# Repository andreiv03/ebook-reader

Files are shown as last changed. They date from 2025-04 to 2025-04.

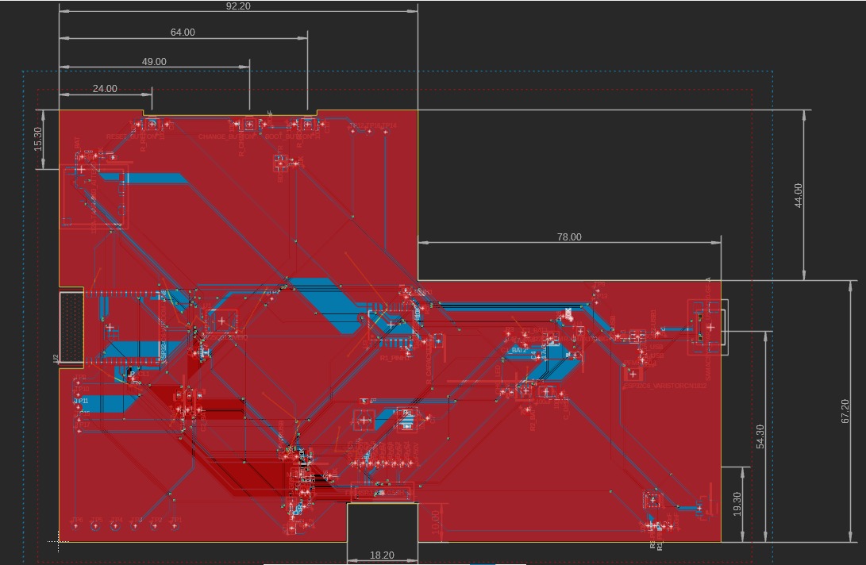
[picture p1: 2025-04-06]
images/pcb.jpg

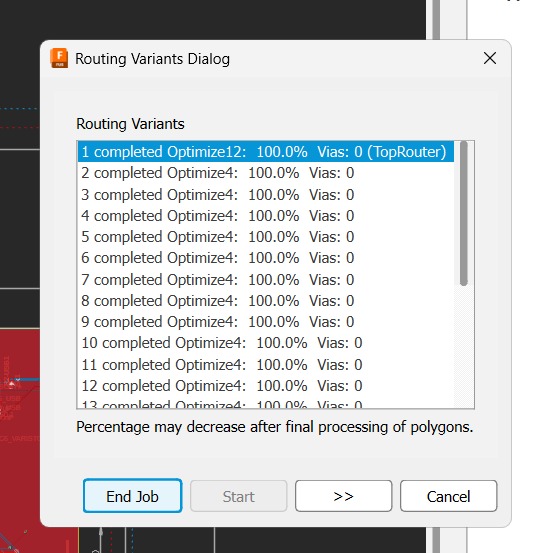
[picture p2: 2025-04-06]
images/autorouter.jpg

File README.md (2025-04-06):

# OpenBook E-book Reader

#### Autor: Voicu Andrei-Silviu

## Descriere generală

OpenBook este un e-reader open-source construit în jurul microcontrollerului ESP32-C6. Dispozitivul folosește un ecran e-paper de 7.5", senzori de mediu, monitorizare baterie și conectivitate USB-C & Wi-Fi.

## Diagramă bloc

```plaintext
         +---------------------+
         |      Li-Po Cell     |
         +---------+-----------+
                   |
                   v
         +---------------------+
         |   Battery Charger   |  <--- USB-C 5V
         |    MCP73832 IC      |
         +---------+-----------+
                   |
                   v
         +---------------------+
         |   3.3V Regulator    | ---> VCC (3.3V Rail)
         +---------+-----------+
                   |
        +----------+-----------+-----------------------+
        |          |           |                       |
        v          v           v                       v
   +---------+ +------------+ +------------------+ +------------------+
   | ESP32-C3| | E-Ink Disp | |   BME688 Sensor  | |   Push Buttons   |
   |   -C6   | |  (SPI 4W)  | |    (I2C Comm)    | |  (GPIO + RC net) |
   +----+----+ +------------+ +--------+---------+ +--------+---------+
        |                           ^                        ^
        |                           |                        |
        |                     Pull-up Res.             Debounce Filter
        |
        v
   +-----------------------------+
   |     USB Type-C Connector    |
   | ↔ USB Data to ESP32 UART    |
   |    + ESD & Termination      |
   +-----------------------------+
```

## Listă de componente (BOM)

| Componenta | Link | Datasheet
| --- | --- |---|
|BUTTON_CUSYOMV1|https://industry.panasonic.com/global/en/downloads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|https://industry.panasonic.com/global/en/downloads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
|ESP32_WROVER_EAGLE-LTSPICE_CC0402|https://componentsearchengine.com/part-view/CC0402MRX5R5BB106/YAGEO|https://componentsearchengine.com/Datasheets/2/CC0402MRX5R5BB106.pdf
| QWIIC_CONNECTORJS-1MM | https://www.snapeda.com/parts/PRT-14417/SparkFun/view-part/ |https://www.snapeda.com/parts/PRT-14417/SparkFun%20Electronics/datasheet/
|112A-TAAR-R03_ATTEND|https://store.comet.bg/en/Catalogue/Product/43497/|https://store.comet.bg/en/Catalogue/Product/43497/|
|ADAFRUIT_LEDCHIP-LED0603|https://www.snapeda.com/parts/KP-1608SURCK/Kingbright/view-part/?ref=search&t=LED%200603|https://www.snapeda.com/parts/KP-1608SURCK/Kingbright/datasheet/
|744043680IND_4828-WE-TPC_WRE|https://www.digikey.sg/en/models/1638515|https://www.we-online.com/components/products/datasheet/744043680.pdf
|ESP32_WROVER_EAGLE-LTSPICE_CC0402|https://componentsearchengine.com/Datasheets/2/CC0402MRX5R5BB106.pdf|https://componentsearchengine.com/part-view/CC0402MRX5R5BB106/YAGEO|
|CPH3225A|https://www.snapeda.com/parts/CPH3225A/Seiko+Instruments/view-part/?ref=eda|https://www.snapeda.com/parts/CPH3225A/Seiko%20Instruments/datasheet/|
|DS3231SN|https://www.snapeda.com/parts/DS3231SN%23/Analog+Devices/view-part/?ref=eda|https://www.snapeda.com/parts/DS3231SN%23/Analog%20Devices/datasheet/|
|SJ|https://grabcad.com/library/solder-jumpers-1||
|CPH3225A|https://www.snapeda.com/parts/CPH3225A/Seiko+Instruments/view-part/?ref=eda|https://www.snapeda.com/parts/CPH3225A/Seiko%20Instruments/datasheet/|
|MCP73831|https://www.digikey.com/en/models/1874108|https://ww1.microchip.com/downloads/aemDocuments/documents/APID/ProductDocuments/DataSheets/MCP73831-Family-Data-Sheet-DS20001984H.pdf|
|RCL_CPOL-EUCT3528|https://ro.mouser.com/ProductDetail/Vishay-Sprague/TR3B106K025C1300?qs=jCGqFXxTmLdffnuDkXzk1g%3D%3D|https://www.vishay.com/docs/40080/tr3.pdf|
|ESP32_WROVER_BME680_BME680|https://www.snapeda.com/parts/BME680/Bosch/view-part/?welcome=home|https://www.snapeda.com/parts/BME680/Bosch%20Sensortec/datasheet/|
|ESP32_WROVER_SPARKFUN-DISCRETESEMI_MOSFET_PCH-DMG2305UX-7|https://componentsearchengine.com/part-view/DMG2305UX-7/Diodes%20Incorporated|https://www.diodes.com//assets/Datasheets/DMG2305UX.pdf|
|BD5229G-TR|https://componentsearchengine.com/part-view/BD5229G-TR/ROHM%20Semiconductor|https://datasheet.datasheetarchive.com/originals/distributors/Datasheets_SAMA/f2b9741ef86007909f138d561a359946.pdf|
|ESP32C6_VARISTORCN1812|https://www.mouser.co.uk/ProductDetail/EPCOS-TDK/B72520T0350K062?qs=dEfas%2FXlABIszF52uu7vrg%3D%3D|https://www.tdk-electronics.tdk.com/inf/75/db/CTVS_14/Surge_protection_series.pdf|
|USBLC6-2SC6Y|https://www.snapeda.com/parts/USBLC6-2SC6Y/STMicroelectronics/view-part/?ref=eda|https://www.snapeda.com/parts/USBLC6-2SC6Y/STMicroelectronics/datasheet/|
|W25Q512JVEIQ|https://www.snapeda.com/parts/W25Q512JVEIQ/Winbond+Electronics/view-part/?ref=eda|https://www.snapeda.com/parts/W25Q512JVEIQ/Winbond%20Electronics/datasheet/|
|XC6220A331MR-G|https://componentsearchengine.com/part-view/XC6220A331MR-G/Torex|https://product.torexsemi.com/system/files/series/xc6220.pdf|
|ESP32-C6-WROOM-1-N8|https://www.snapeda.com/parts/ESP32-C6-WROOM-1-N8/Espressif+Systems/view-part/?ref=eda|https://www.snapeda.com/parts/ESP32-C6-WROOM-1-N8/Espressif%20Systems/datasheet/
| ESP32_WROVER_EAGLE-LTSPICE_RR0402  | https://www.snapeda.com/parts/RC0402FR-07226RL/Yageo/view-part/ |https://www.snapeda.com/parts/RC0402FR-07226RL/Yageo/datasheet/
|FH34SRJ-24S-0.5SH_99_|https://componentsearchengine.com/part-view/XC6220A331MR-G/Torex|https://product.torexsemi.com/system/files/series/xc6220.pdf|
|SAMACSYS_PARTS_USB4110-GF-A|https://componentsearchengine.com/part-view/USB4110-GF-A/GCT%20(GLOBAL%20CONNECTOR%20TECHNOLOGY)|https://gct.co/files/drawings/usb4110.pdf|
|MAX17048G+T10|https://www.snapeda.com/parts/MAX17048G+T10/Analog+Devices/view-part/?ref=eda|https://www.snapeda.com/parts/MAX17048G+T10/Analog%20Devices/datasheet/|
|PGB1010603MR|https://www.snapeda.com/parts/PGB1010603MR/Littelfuse/view-part/?ref=eda|https://www.snapeda.com/parts/PGB1010603MR/Littelfuse%20Inc./datasheet/|
|SI1308EDL-T1-GE3|https://componentsearchengine.com/part-view/SI1308EDL-T1-GE3/Vishay|https://componentsearchengine.com/Datasheets/1/SI1308EDL-T1-GE3.pdf|
|MBR0530|https://ro.mouser.com/ProductDetail/KYOCERA-AVX/SD0805S020S1R0?qs=jCA%252BPfw4LHbpkAoSnwrdjw%3D%3D|https://ro.mouser.com/datasheet/2/40/schottky-3165252.pdf|

## Componente principale

#### ESP32-C6-WROOM-1-N8
- MCU principal, Wi-Fi 6, Bluetooth 5
- Interfețe: SPI, I2C, UART, GPIO
- 160MHz, 512KB SRAM, 8MB Flash

#### Senzor BME688
- Măsoară: temperatură, umiditate, presiune, VOC
- I2C, consum redus: <1mA

#### Ecran E-Paper
- Diagonală: 7.5”
- Conectare prin SPI
- Consum 0 în stare statică

#### Sistem de Alimentare
- Baterie: 3.7V Li-Po 2500mAh
- Încărcare: MCP73831, max 1A
- Monitorizare: MAX17048 (Fuel Gauge)
- Consum tipic:
- Activ: ~150mA
- Standby: ~10mA
- Deep Sleep: <50µA
- Autonomie: ~250h la 10mA

#### Conectivitate USB-C
- Încărcare & date (USB 2.0)
- Protecție ESD: USBLC6-2SC6Y

## Alocare pini ESP32-C6

| *Pin ESP32-C6* | *Funcție* | *Componentă* | *Rol* |
|---|---|---|---|
| GPIO0 | BOOT_BUTTON | Buton | Mod boot la inițializare |
| GPIO1 | RESET_BUTTON | Buton | Reset manual |
| GPIO2 | CHANGE_BUTTON | Buton | Schimbare meniuri |
| GPIO3 | EPD_CS | Display E-Paper | Chip Select pentru SPI |
| GPIO4 | EPD_DC | Display E-Paper | Control Date/Comenzi |
| GPIO5 | EPD_RST | Display E-Paper | Reset display |
| GPIO6 | EPD_BUSY | Display E-Paper | Detectare stare refresh |
| GPIO7 | SPI_MOSI | Display, Flash, SD | Linii de date SPI |
| GPIO8 | SPI_MISO | Display, Flash, SD | Linie de date SPI (citire) |
| GPIO9 | SPI_SCK | Display, Flash, SD | Semnal de ceas SPI |
| GPIO10 | FLASH_CS | Memorie Flash | Chip Select pentru memorie |
| GPIO11 | SD_CS | Card Micro SD | Chip Select pentru card SD |
| GPIO12 | I2C_SDA | BME680, MAX17048, DS3231 | Linie de date pentru I2C |
| GPIO13 | I2C_SCL | BME680, MAX17048, DS3231 | Linie de ceas pentru I2C |
| GPIO14 | CHG_LED | LED | Indică procesul de încărcare |
| GPIO15 | UART_TX | Debugging | Transmitere date seriale |
| GPIO16 | UART_RX | Debugging | Recepție date seriale |
| GPIO17 | USB_D+ | USB-C | Linie de date USB pozitivă |
| GPIO18 | USB_D- | USB-C | Linie de date USB negativă |

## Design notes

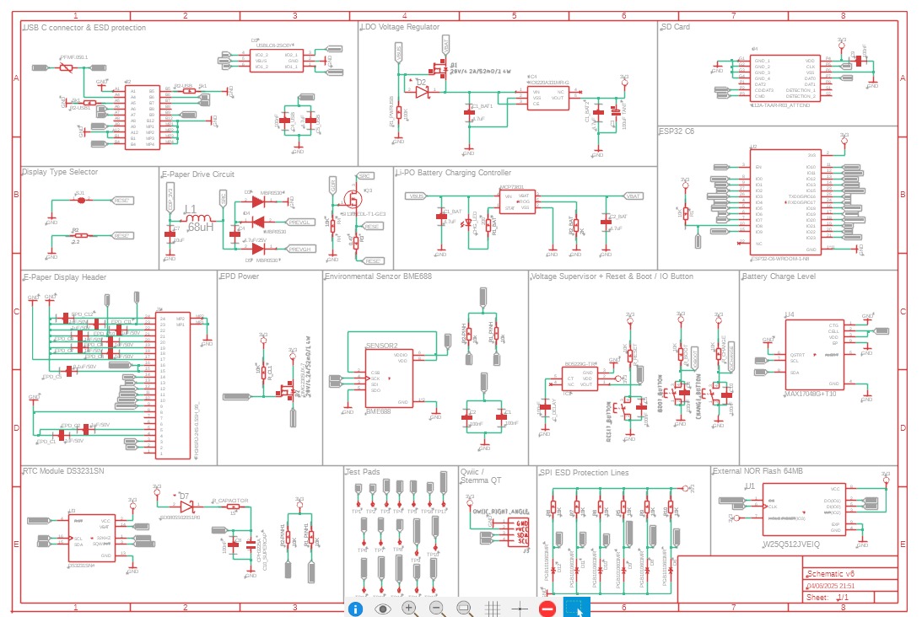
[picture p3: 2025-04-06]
images/schematic.jpg

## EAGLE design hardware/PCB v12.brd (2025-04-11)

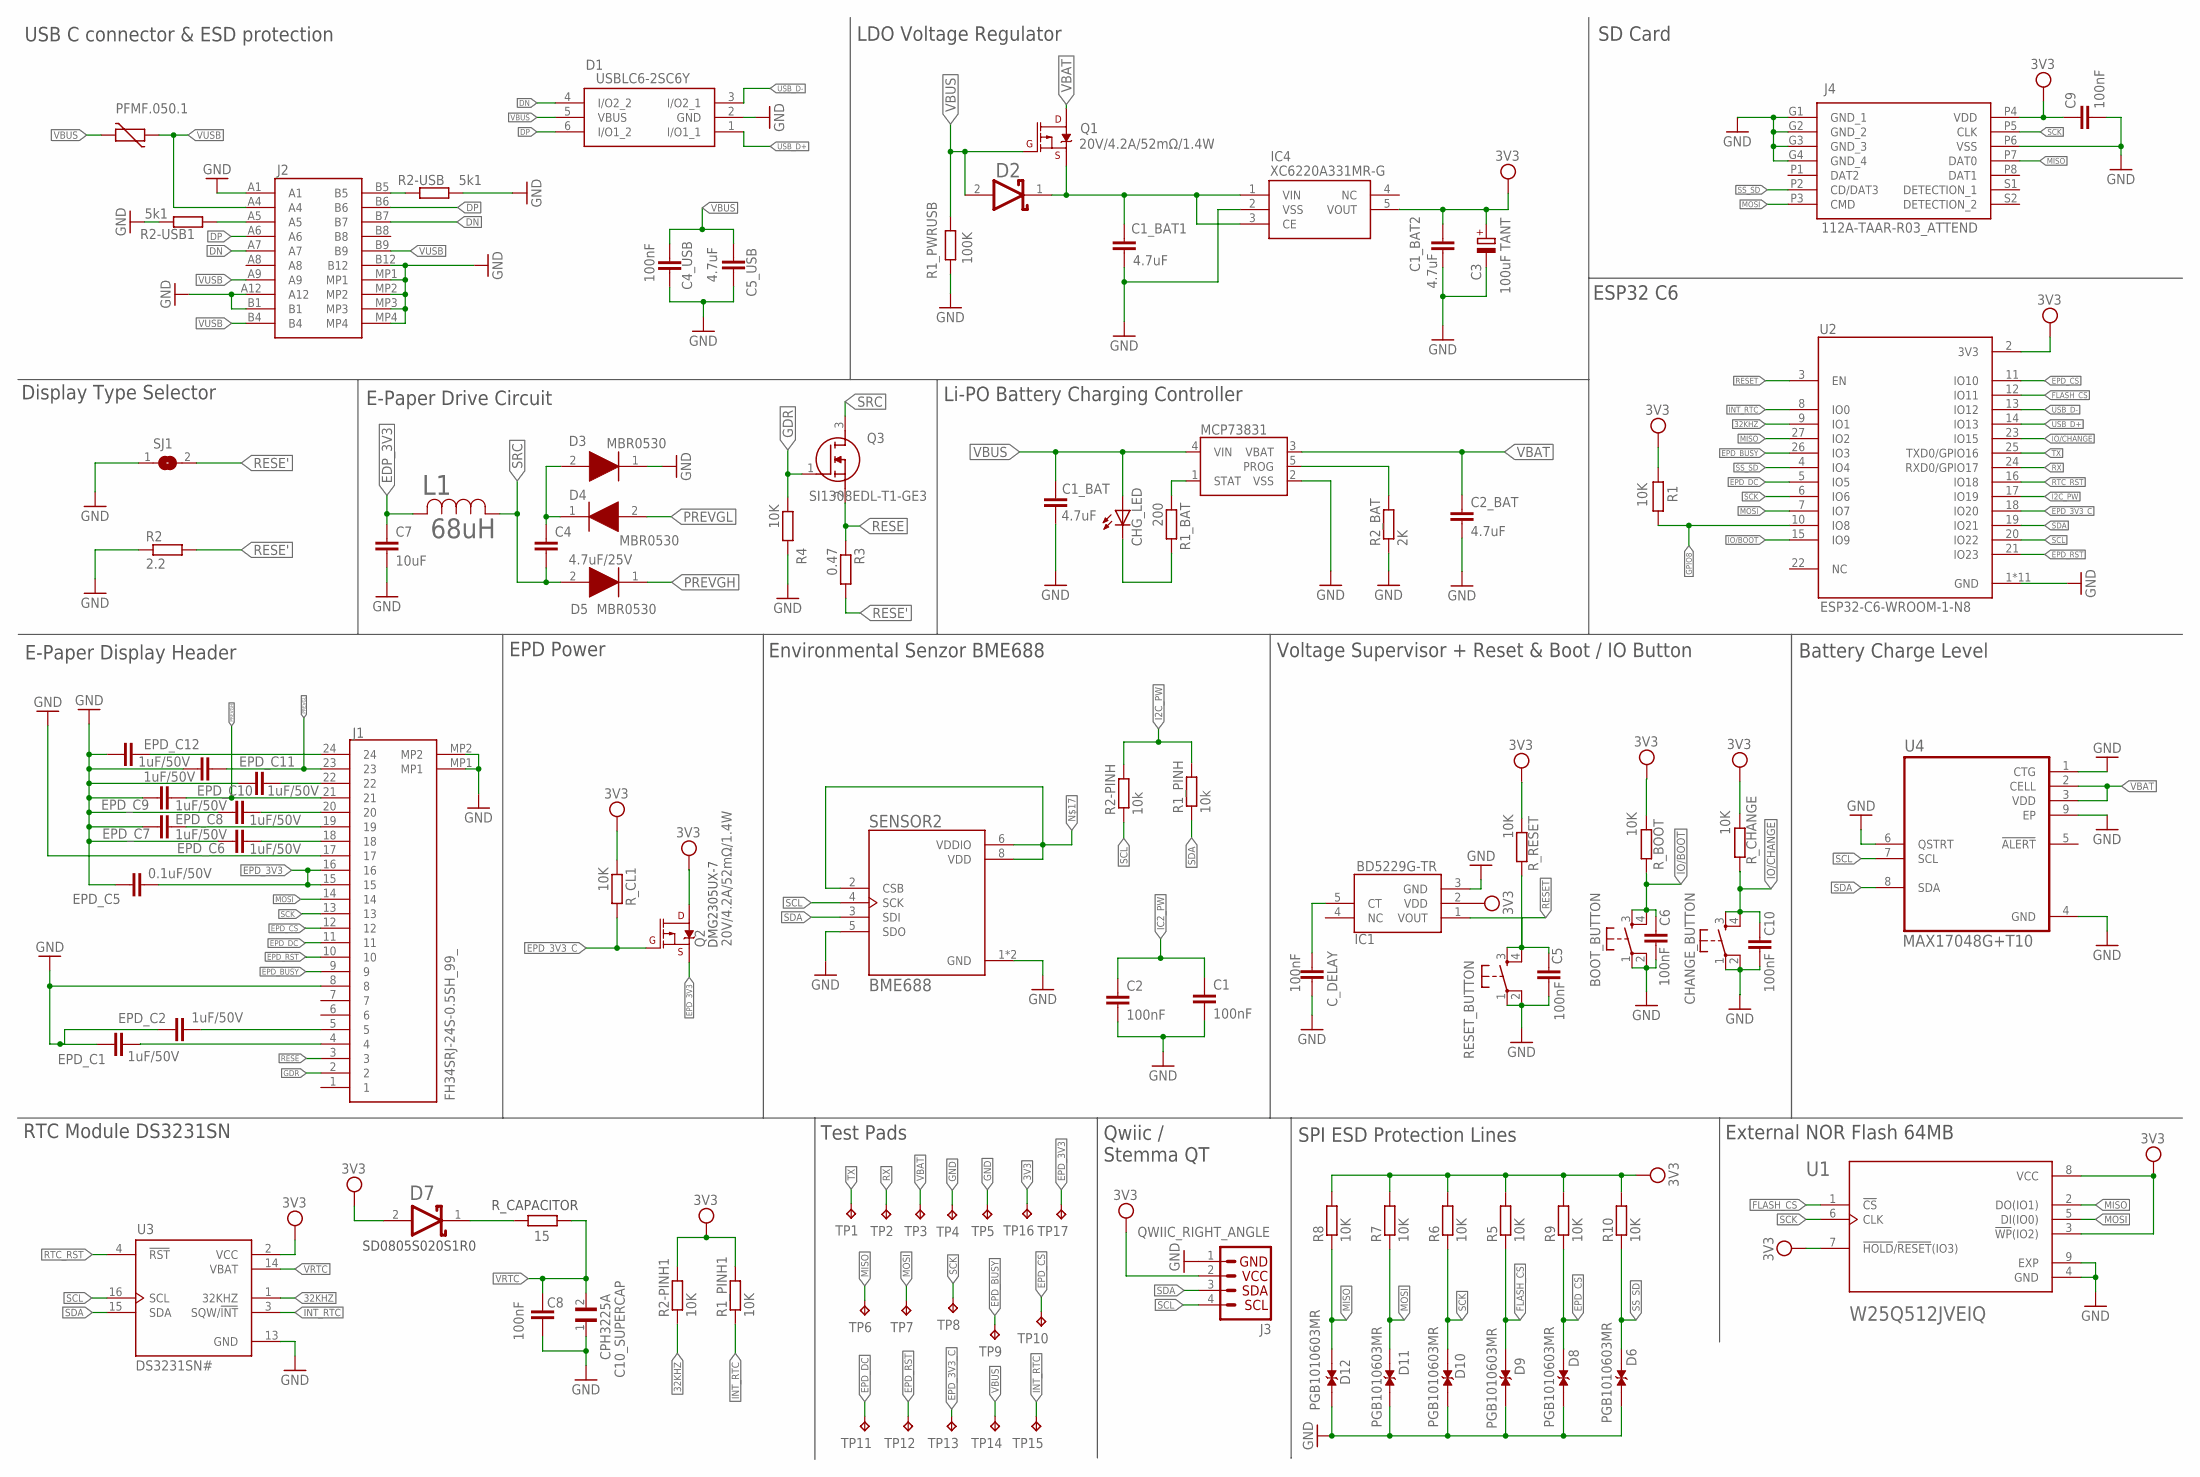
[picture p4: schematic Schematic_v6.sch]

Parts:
BOOT_BUTTON: BUTTON_CUSYOMV1; MYBUTTON
C1, C2, C4_USB, C8, C9: 100nF; ESP32_WROVER_EAGLE-LTSPICE_C0402
C1_BAT, C1_BAT1, C1_BAT2, C2_BAT, C5_USB: 4.7uF; ESP32_WROVER_EAGLE-LTSPICE_C0402
C3: 100uF TANT; RCL_CT3528
C4: 4.7uF/25V; ESP32_WROVER_EAGLE-LTSPICE_C0402
C5, C6, C10: 100nF; EAGLE-LTSPICE_C0402
C7: 10uF; ESP32_WROVER_EAGLE-LTSPICE_C0402
C10_SUPERCAP: CPH3225A; CAPCP3225X100N
CHANGE_BUTTON: BUTTON_CUSYOMV1; MYBUTTON
CHG_LED: CHG; ADAFRUIT_CHIP-LED0603
C_DELAY: 100nF; ESP32_WROVER_EAGLE-LTSPICE_C0402
D1: USBLC6-2SC6Y; SOT95P280X145-6N
D2, D7: ESP32_WROVER_AVX---SD0805S020S1R0_AVX_SD0805S020S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; ESP32_WROVER_AVX---SD0805S020S1R0_AVX_SD0805S020S1R0_0
D3, D4, D5: MBR0530; SOD3716X135N
D6, D8, D9, D10, D11, D12: PGB1010603MR; DIOC1608X36N
EPD_C1, EPD_C2, EPD_C6, EPD_C7, EPD_C8, EPD_C9, EPD_C10, EPD_C11, EPD_C12: 1uF/50V; EAGLE-LTSPICE_C0402
EPD_C5: 0.1uF/50V; EAGLE-LTSPICE_C0402
IC1: BD5229G-TR; SOT95P280X125-5N
IC4: XC6220A331MR-G; SOT95P280X120-5N
J1: FH34SRJ-24S-0.5SH_99_; FH34SRJ24S05SH99
J2: SAMACSYS_PARTS_USB4110-GF-A; SAMACSYS_PARTS_USB4110GFA
J3: QWIIC_RIGHT_ANGLE; JST04_1MM_RA
J4: 112A-TAAR-R03_ATTEND; 112ATAARR03ATTEND
L1: 68uH; IND_4828-WE-TPC_WRE
MCP73831: ESP32_WROVER_SPARKFUN-IC-POWER_MCP73831; ESP32_WROVER_SPARKFUN-IC-POWER_SOT23-5
PFMF.050.1: ESP32C6_VARISTORCN1812; ESP32C6_VARISTOR_CT/CN1812
Q1, Q2: 20V/4.2A/52mΩ/1.4W; ESP32_WROVER_SPARKFUN-DISCRETESEMI_SOT23-3
Q3: SI1308EDL-T1-GE3; SOT65P210X110-3N
R1, R1_PINH1, R2-PINH1, R4, R5, R6, R7, R8, R9, R10: 10K; ESP32_WROVER_EAGLE-LTSPICE_R0402
R1_BAT: 200; ESP32_WROVER_EAGLE-LTSPICE_R0402
R1_PINH, R2-PINH: 10k; ESP32_WROVER_EAGLE-LTSPICE_R0402
R1_PWRUSB: 100K; ESP32_WROVER_EAGLE-LTSPICE_R0402
R2: 2.2; ESP32_WROVER_EAGLE-LTSPICE_R0402
R2-USB, R2-USB1: 5k1; ESP32_WROVER_EAGLE-LTSPICE_R0402
R2_BAT: 2K; ESP32_WROVER_EAGLE-LTSPICE_R0402
R3: 0.47; ESP32_WROVER_EAGLE-LTSPICE_R0402
RESET_BUTTON: BUTTON_CUSYOMV1; MYBUTTON
R_BOOT: 10K; ESP32_WROVER_EAGLE-LTSPICE_R0402
R_CAPACITOR: 15; ESP32_WROVER_EAGLE-LTSPICE_R0402
R_CHANGE: 10K; ESP32_WROVER_EAGLE-LTSPICE_R0402
R_CL1: 10K; ESP32_WROVER_EAGLE-LTSPICE_R0402
R_RESET: 10K; ESP32_WROVER_EAGLE-LTSPICE_R0402
SENSOR2: BME688; ESP32_WROVER_BME680_PSON80P300X300X100-8N
SJ1: SJ1; SJ
TP1, TP2, TP3, TP4, TP5, TP6, TP7, TP8, TP9, TP10, TP11, TP12, TP13, TP14, TP15, TP16, TP17: TPTP20R; TP20R
U1: W25Q512JVEIQ; SON127P600X800X80-9N
U2: ESP32-C6-WROOM-1-N8; XCVR_ESP32-C6-WROOM-1-N8
U3: DS3231SN#; SOIC127P1032X265-16N
U4: MAX17048G+T10; SON50P200X200X80-9N

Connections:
3V3: C1_BAT2.1, C3.+, C9.1, D7.2 (ANODE), IC4.5 (VOUT), J3.2, J4.P4 (VDD), Q2.3 (D), R1.1, R1_PINH1.2, R2-PINH1.2, R5.2, R6.2, R7.2, R8.2, R9.2, R10.2, R_BOOT.2, R_CHANGE.2, R_CL1.1, R_RESET.2, TP16.TP, U1.3 (!WP!(IO2)), U1.7 (!HOLD!/!RESET!(IO3)), U1.8 (VCC), U2.2 (3V3), U3.2 (VCC)
32KHZ: R2-PINH1.1, U2.9 (IO1), U3.1 (32KHZ)
DN: D1.4 (I/O2_2), J2.A7, J2.B7
DP: D1.6 (I/O1_2), J2.A6, J2.B6
EDP_3V3: C7.1, L1.2
EPD_3V3: EPD_C5.2, J1.15, J1.16, Q2.2 (S), TP17.TP
EPD_3V3_C: Q2.1 (G), R_CL1.2, TP13.TP, U2.18 (IO20)
EPD_BUSY: J1.9, TP9.TP, U2.26 (IO3)
EPD_CS: D8.1, J1.12, R9.1, TP10.TP, U2.11 (IO10)
EPD_DC: J1.11, TP11.TP, U2.5 (IO5)
EPD_RST: J1.10, TP12.TP, U2.21 (IO23)
FLASH_CS: D9.1, R5.1, U1.1 (!CS), U2.12 (IO11)
GDR: J1.2, Q3.1 (G), R4.1
GND: BOOT_BUTTON.1, BOOT_BUTTON.2, C1.2, C1_BAT.2, C1_BAT1.2, C1_BAT2.2, C2.2, C2_BAT.2, C3.-, C4_USB.2, C5.2, C5_USB.2, C6.2, C7.2, C8.2, C9.2, C10.2, C10_SUPERCAP.1, CHANGE_BUTTON.1, CHANGE_BUTTON.2, C_DELAY.2, D1.2 (GND), D3.1 (K), D6.2, D8.2, D9.2, D10.2, D11.2, D12.2, EPD_C1.1, EPD_C2.1, EPD_C5.1, EPD_C6.1, EPD_C7.1, EPD_C8.1, EPD_C9.1, EPD_C10.1, EPD_C11.1, EPD_C12.1, IC1.3 (GND), IC4.2 (VSS), J1.8, J1.17, J1.MP1, J1.MP2, J2.A1, J2.A12, J2.B1, J2.B12, J2.MP1, J2.MP2, J2.MP3, J2.MP4, J3.1, J4.G1 (GND_1), J4.G2 (GND_2), J4.G3 (GND_3), J4.G4 (GND_4), J4.P6 (VSS), MCP73831.2 (VSS), R1_PWRUSB.1, R2.1, R2-USB.2, R2-USB1.1, R2_BAT.1, R4.2, RESET_BUTTON.1, RESET_BUTTON.2, SENSOR2.1 (GND), SENSOR2.5 (SDO), SENSOR2.7 (GND), SJ1.1, TP4.TP, TP5.TP, U1.4 (GND), U1.9 (EXP), U2.1 (GND), U2.28 (GND), U2.29_1 (GND), U2.29_2 (GND), U2.29_3 (GND), U2.29_4 (GND), U2.29_5 (GND), U2.29_6 (GND), U2.29_7 (GND), U2.29_8 (GND), U2.29_9 (GND), U3.13 (GND), U4.1 (CTG), U4.4 (GND), U4.6 (QSTRT), U4.9 (EP)
GPIO8: R1.2, U2.10 (IO8)
I2C_PW: R1_PINH.2, R2-PINH.2, U2.17 (IO19)
IC2_PW: C1.1, C2.1
INT_RTC: R1_PINH1.1, TP15.TP, U2.8 (IO0), U3.3 (SQW/!INT)
IO/BOOT: BOOT_BUTTON.3, BOOT_BUTTON.4, C6.1, R_BOOT.1, U2.15 (IO9)
IO/CHANGE: C10.1, CHANGE_BUTTON.3, CHANGE_BUTTON.4, R_CHANGE.1, U2.23 (IO15)
MISO: D12.1, J4.P7 (DAT0), R8.1, TP6.TP, U1.2 (DO(IO1)), U2.27 (IO2)
MOSI: D11.1, J1.14, J4.P3 (CMD), R7.1, TP7.TP, U1.5 (DI(IO0)), U2.7 (IO7)
unnamed: EPD_C10.2, J1.22
unnamed: C1_BAT1.1, D2.1 (CATHODE), IC4.1 (VIN), IC4.3 (CE), Q1.2 (S)
unnamed: MCP73831.5 (PROG), R2_BAT.2
unnamed: EPD_C8.2, J1.20
unnamed: J2.B5, R2-USB.1
unnamed: C4.1, D3.2 (A), D4.1 (K)
unnamed: MCP73831.1 (STAT), R1_BAT.1
unnamed: CHG_LED.C, R1_BAT.2
unnamed: EPD_C7.2, J1.19
unnamed: J2.A5, R2-USB1.2
unnamed: EPD_C6.2, J1.18
unnamed: EPD_C12.2, J1.24
unnamed: D7.1 (CATHODE), R_CAPACITOR.2
unnamed: EPD_C2.2, J1.5
unnamed: EPD_C1.2, J1.4
unnamed: SENSOR2.2 (CSB), SENSOR2.6 (VDDIO), SENSOR2.8 (VDD)
unnamed: C_DELAY.1, IC1.5 (CT)
PREVGH: D5.1 (K), EPD_C9.2, J1.21
PREVGL: D4.2 (A), EPD_C11.2, J1.23
RESE: J1.3, Q3.2 (S), R3.1
RESE': R2.2, R3.2, SJ1.2
RESET: C5.1, IC1.1 (VOUT), RESET_BUTTON.3, RESET_BUTTON.4, R_RESET.1, U2.3 (EN)
RTC_RST: U2.16 (IO18), U3.4 (!RST)
RX: TP2.TP, U2.24 (RXD0/GPIO17)
SCK: D10.1, J1.13, J4.P5 (CLK), R6.1, TP8.TP, U1.6 (CLK), U2.6 (IO6)
SCL: J3.4, R2-PINH.1, SENSOR2.4 (SCK), U2.20 (IO22), U3.16 (SCL), U4.7 (SCL)
SDA: J3.3, R1_PINH.1, SENSOR2.3 (SDI), U2.19 (IO21), U3.15 (SDA), U4.8 (SDA)
SRC: C4.2, D5.2 (A), L1.1, Q3.3 (D)
SS_SD: D6.1, J4.P2 (CD/DAT3), R10.1, U2.4 (IO4)
TX: TP1.TP, U2.25 (TXD0/GPIO16)
USB_D+: D1.1 (I/O1_1), U2.14 (IO13)
USB_D-: D1.3 (I/O2_1), U2.13 (IO12)
VBAT: C2_BAT.1, MCP73831.3 (VBAT), Q1.3 (D), TP3.TP, U4.2 (CELL), U4.3 (VDD)
VBUS: C1_BAT.1, C4_USB.1, C5_USB.1, CHG_LED.A, D1.5 (VBUS), D2.2 (ANODE), MCP73831.4 (VIN), PFMF.050.1.2, Q1.1 (G), R1_PWRUSB.2, TP14.TP
VRTC: C8.1, C10_SUPERCAP.2, R_CAPACITOR.1, U3.14 (VBAT)
VUSB: J2.A4, J2.A9, J2.B4, J2.B9, PFMF.050.1.1

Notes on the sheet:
USB C connector & ESD protection
LDO Voltage Regulator
SD Card
ESP32 C6
Li-PO Battery Charging Controller
Display Type Selector
E-Paper Drive Circuit
Battery Charge Level
External NOR Flash 64MB
E-Paper Display Header
DMG2305UX-7
EPD Power
Environmental Senzor BME688
Voltage Supervisor + Reset & Boot / IO Button
RTC Module DS3231SN
Qwiic / Stemma QT
Test Pads
SPI ESD Protection Lines
SD0805S020S1R0
R_CAPACITOR

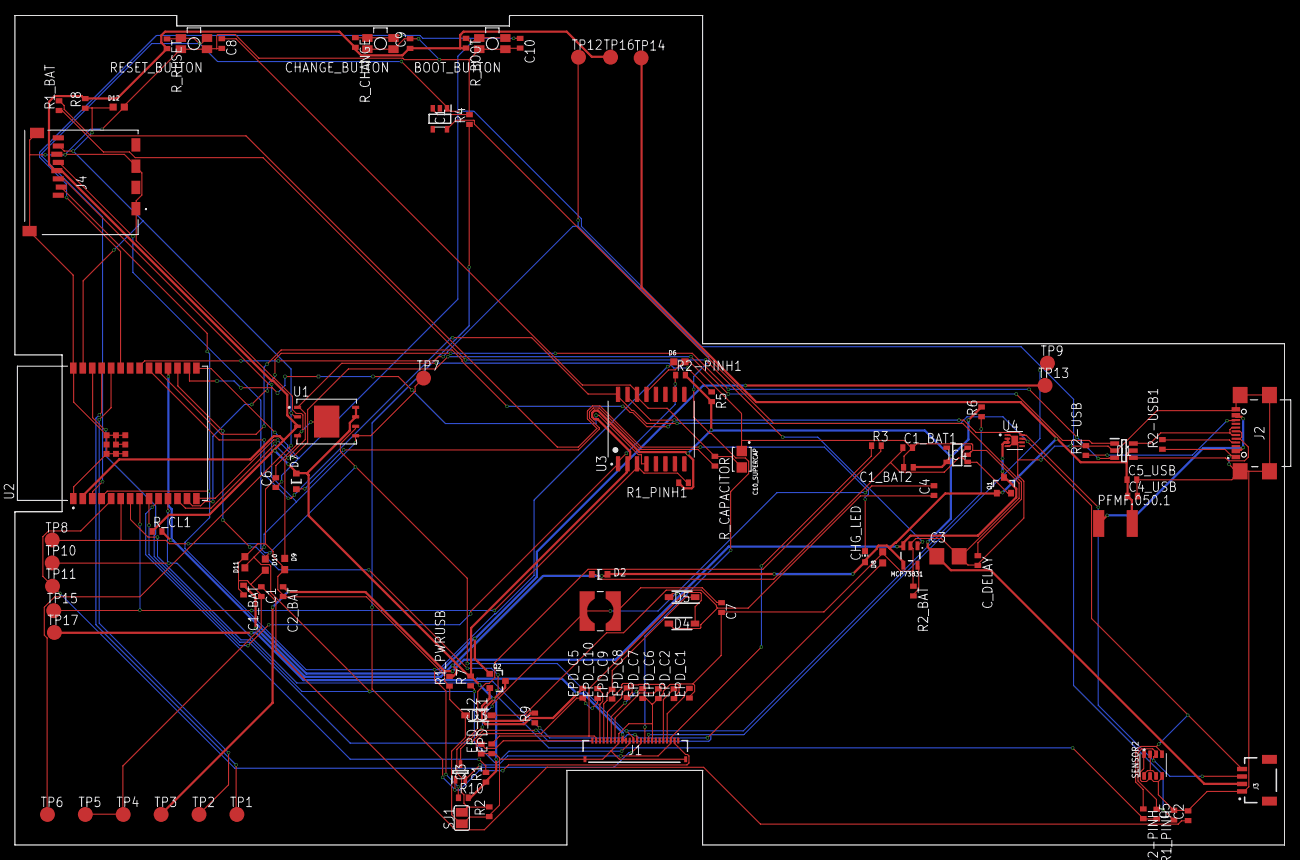
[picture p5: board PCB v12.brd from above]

Board: 2 copper layers, 170.2 x 111.2 mm, 103 parts (0 on the bottom side), 58 nets.

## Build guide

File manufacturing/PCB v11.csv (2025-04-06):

Partlist exported from Fusion Hub: TSC   Project: TSC  Board: PCB v11 at 04/06/2025 14:33
Qty Value                                                                          Device                                                                         Package                                                Parts                                                                                       Description                                                                                                                                                                                                                                                                                                                                                                                                                                                                                          ARROW_PART_NUMBER ARROW_PRICE-STOCK AVAILABILITY CENTROID_NOT_SPECIFIED CHECK_PRICES                                                                           COPYRIGHT                                                DATASHEET                              DESCRIPTION                                                                                        DIGIKEY_DESCRIPTION                                                                                                                                                                                                      DIGIKEY_PART_NUMBER                           HEIGHT                                                                                L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
1   0.1uF/50V                                                                      EAGLE-LTSPICE_CC0402                                                           EAGLE-LTSPICE_C0402                                    EPD_C5                                                                                      CAPACITOR, European symbol                                                                                                                                                                                                                                                                                                                                                                                                                                                                                                                                                                                                                                                                                                                                                                                                                                                                                                                                                                                                                                                                                                                                                                                                           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
1   0.47                                                                           ESP32_WROVER_EAGLE-LTSPICE_RR0402                                              ESP32_WROVER_EAGLE-LTSPICE_R0402                       R3                                                                                          RESISTOR, European symbol                                                                                                                                                                                                                                                                                                                                                                                                                                                                                                                                                                                                                                                                                                                                                                                                                                                                                                                                                                                                                                                                                                                                                                                                            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
1   100K                                                                           ESP32_WROVER_EAGLE-LTSPICE_RR0402                                              ESP32_WROVER_EAGLE-LTSPICE_R0402                       R1_PWRUSB                                                                                   RESISTOR, European symbol                                                                                                                                                                                                                                                                                                                                                                                                                                                                                                                                                                                                                                                                                                                                                                                                                                                                                                                                                                                                                                                                                                                                                                                                            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
3   100nF                                                                          EAGLE-LTSPICE_CC0402                                                           EAGLE-LTSPICE_C0402                                    C5, C6, C10                                                                                 CAPACITOR, European symbol                                                                                                                                                                                                                                                                                                                                                                                                                                                                                                                                                                                                                                                                                                                                                                                                                                                                                                                                                                                                                                                                                                                                                                                                           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
6   100nF                                                                          ESP32_WROVER_EAGLE-LTSPICE_CC0402                                              ESP32_WROVER_EAGLE-LTSPICE_C0402                       C1, C2, C4_USB, C8, C9, C_DELAY                                                             CAPACITOR, European symbol                                                                                                                                                                                                                                                                                                                                                                                                                                                                                                                                                                                                                                                                                                                                                                                                                                                                                                                                                                                                                                                                                                                                                                                                           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
1   100uF TANT                                                                     RCL_CPOL-EUCT3528                                                              RCL_CT3528                                             C3                                                                                          POLARIZED CAPACITOR, European symbol                                                                                                                                                                                                                                                                                                                                                                                                                                                                                                                                                                                                                                                                                                                                                                                                                                                                                                                                                                                                                                                                                                                                                                                                 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

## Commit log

2025-04-06 feat(hw): new
    [PnP_PCB v11_front.csv]
2025-04-11 reupload, no change
    [PCB v11.brd, PCB v12.brd, Schematic v6.sch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]

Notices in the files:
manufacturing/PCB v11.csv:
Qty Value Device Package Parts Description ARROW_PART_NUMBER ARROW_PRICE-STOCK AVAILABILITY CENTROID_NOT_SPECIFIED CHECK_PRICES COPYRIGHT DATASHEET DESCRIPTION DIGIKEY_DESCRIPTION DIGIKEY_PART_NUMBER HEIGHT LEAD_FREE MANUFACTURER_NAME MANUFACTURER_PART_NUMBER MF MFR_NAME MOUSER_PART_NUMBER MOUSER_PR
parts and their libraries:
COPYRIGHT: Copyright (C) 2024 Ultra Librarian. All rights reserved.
